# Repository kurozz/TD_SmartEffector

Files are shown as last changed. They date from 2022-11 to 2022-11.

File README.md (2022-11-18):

# Tree Diagram Smart Effector design files repository.

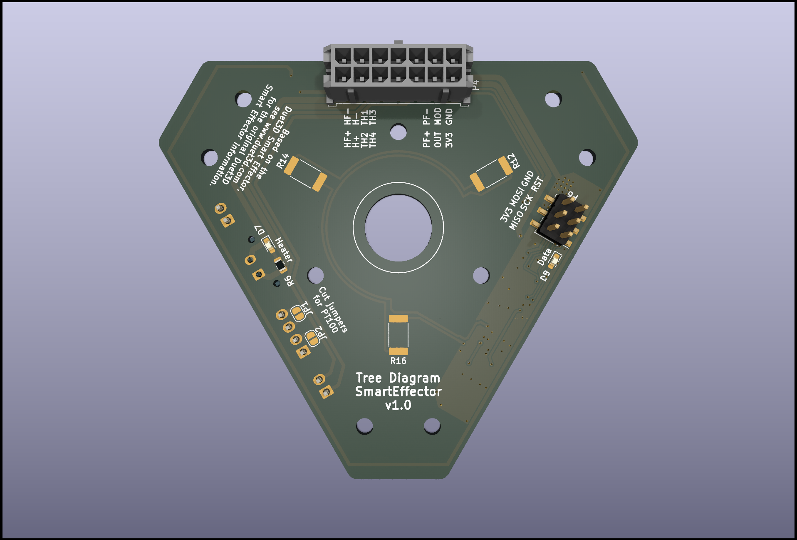
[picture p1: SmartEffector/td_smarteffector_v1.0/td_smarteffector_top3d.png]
Top 3D View

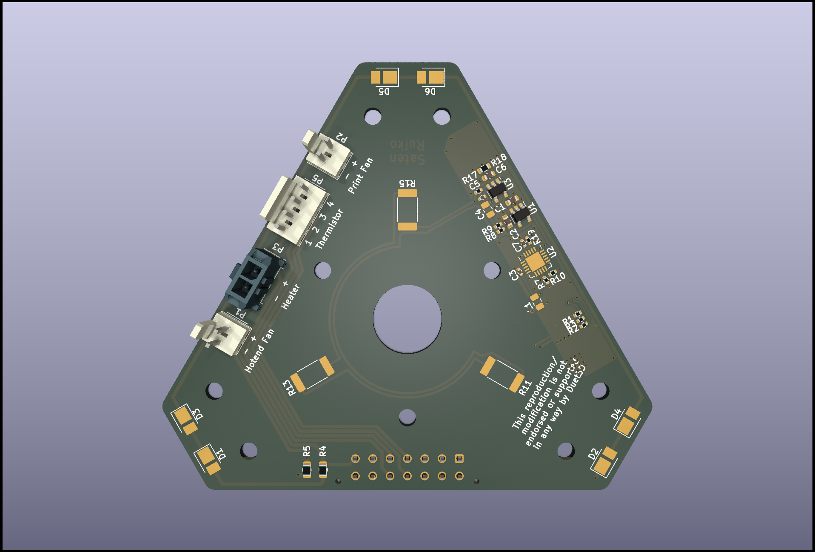
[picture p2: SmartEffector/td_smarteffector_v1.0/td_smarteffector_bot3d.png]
Bottom 3D View


Based on the Duet3D Smart Effector, see www.duet3d.com for the original Duet3D Smart Effector information. This reproduction/modification is not endorsed or supported in any way by Duet3D

This design is meant for 24V, 12V is possible but requires dessoldering LEDs and adding jumpers.

## Changes from the original Smart Effector v3.0:
- Connectors heavily modified
    - All cables from the Duet controller board on a single connector
    - All cables from the effector on the same side of the board
- 6 illumination LEDs instead of 3.
- LEDs are 24V only. You can use 12V by soldering jumpers in place of 3 LEDs.
- Different regulator and amplifier to be easier to source.
- Works with the same firmware as Smart Effector v3.0.

Tree Diagram Smart Effector

Design by Kuro.

Original Design by Tony Lock and David Crocker

LICENSE: see the LICENSE file in the repository

Documentation: https://docs.duet3d.com/Duet3D_hardware/Accessories/Smart_Effector

Developed in KiCAD v6: https://www.kicad.org/

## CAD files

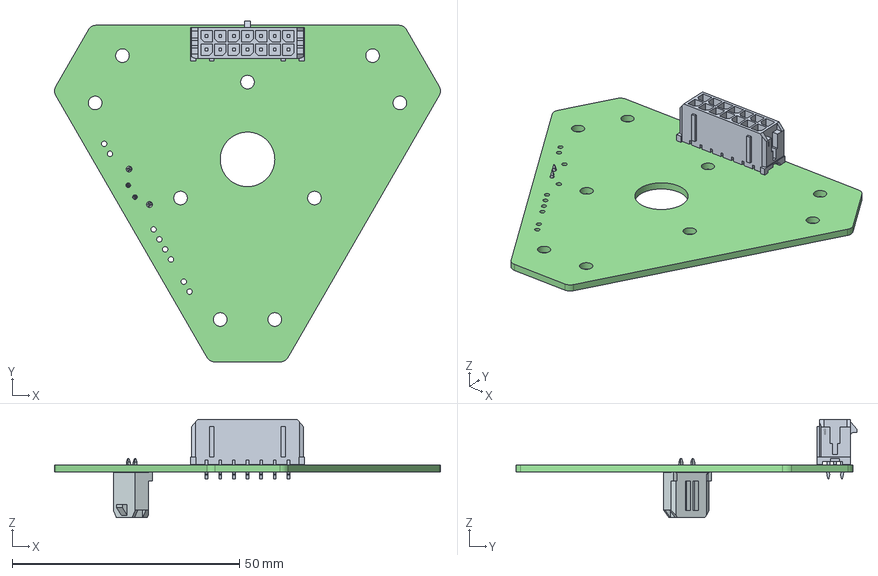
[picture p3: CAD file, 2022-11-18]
SmartEffector/td_smarteffector_v1.0/td_smarteffector.step
84.9 x 75.0 x 21.7 mm
td_smarteffector PCB

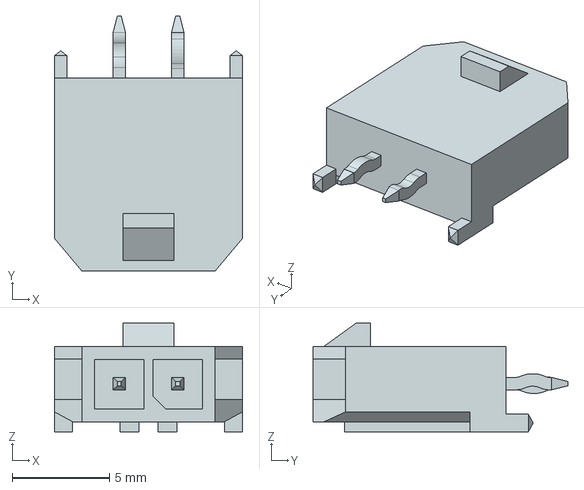
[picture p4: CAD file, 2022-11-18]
SmartEffector/td_smarteffector_v1.0/3dmodel/436500215.stp
9.65 x 13.1 x 5.57 mm

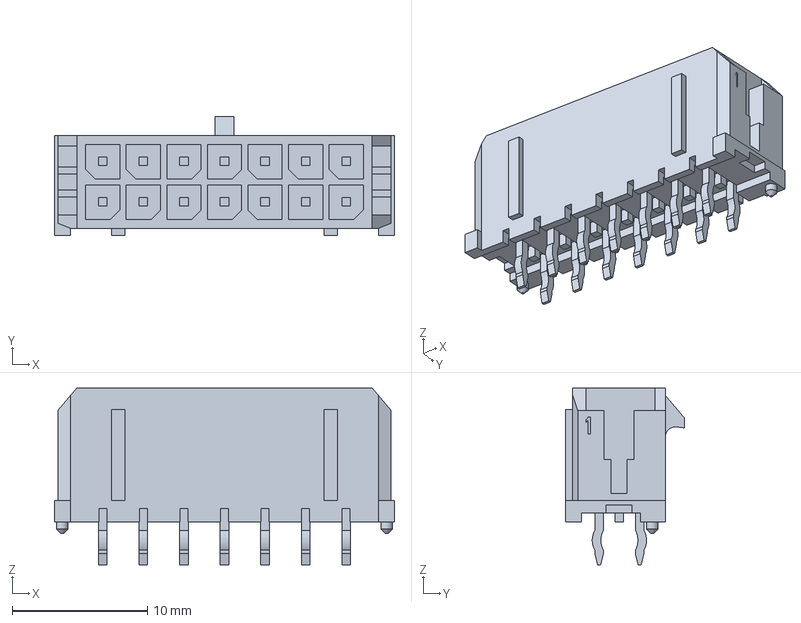
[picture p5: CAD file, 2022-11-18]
SmartEffector/td_smarteffector_v1.0/3dmodel/430451412.stp
25.1 x 8.77 x 13.1 mm

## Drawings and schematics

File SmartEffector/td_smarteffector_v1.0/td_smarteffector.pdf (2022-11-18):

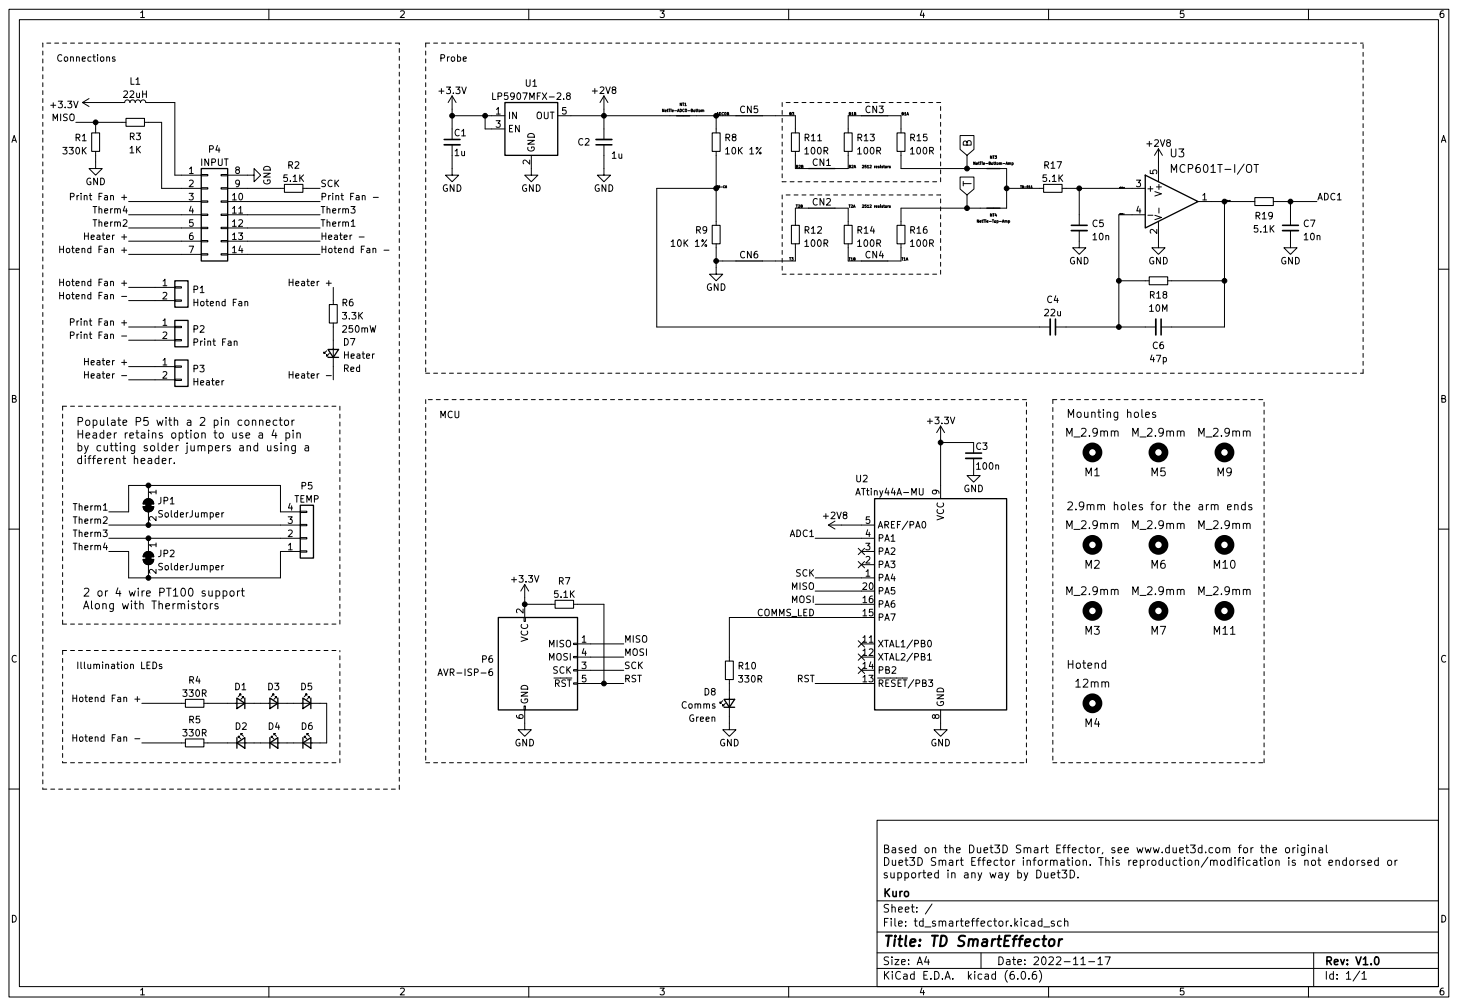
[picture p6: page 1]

Header retains option to use a 4 pin
by cutting solder jumpers and using a

Illumination LEDs 2 or 4 wire PT100 support
Along with Thermistors

2 SCK 3 MOSI 4 ~{RST} 5 GND

supported in any way by Duet3D. GND

File: td_smarteffector.kicad_sch Sheet: / Kuro Based on the Duet3D Smart Effector, see www.duet3d.com for the original

Duet3D Smart Effector information. This reproduction/modification is not endorsed or

Id: 1/1 Title: TD SmartEffector

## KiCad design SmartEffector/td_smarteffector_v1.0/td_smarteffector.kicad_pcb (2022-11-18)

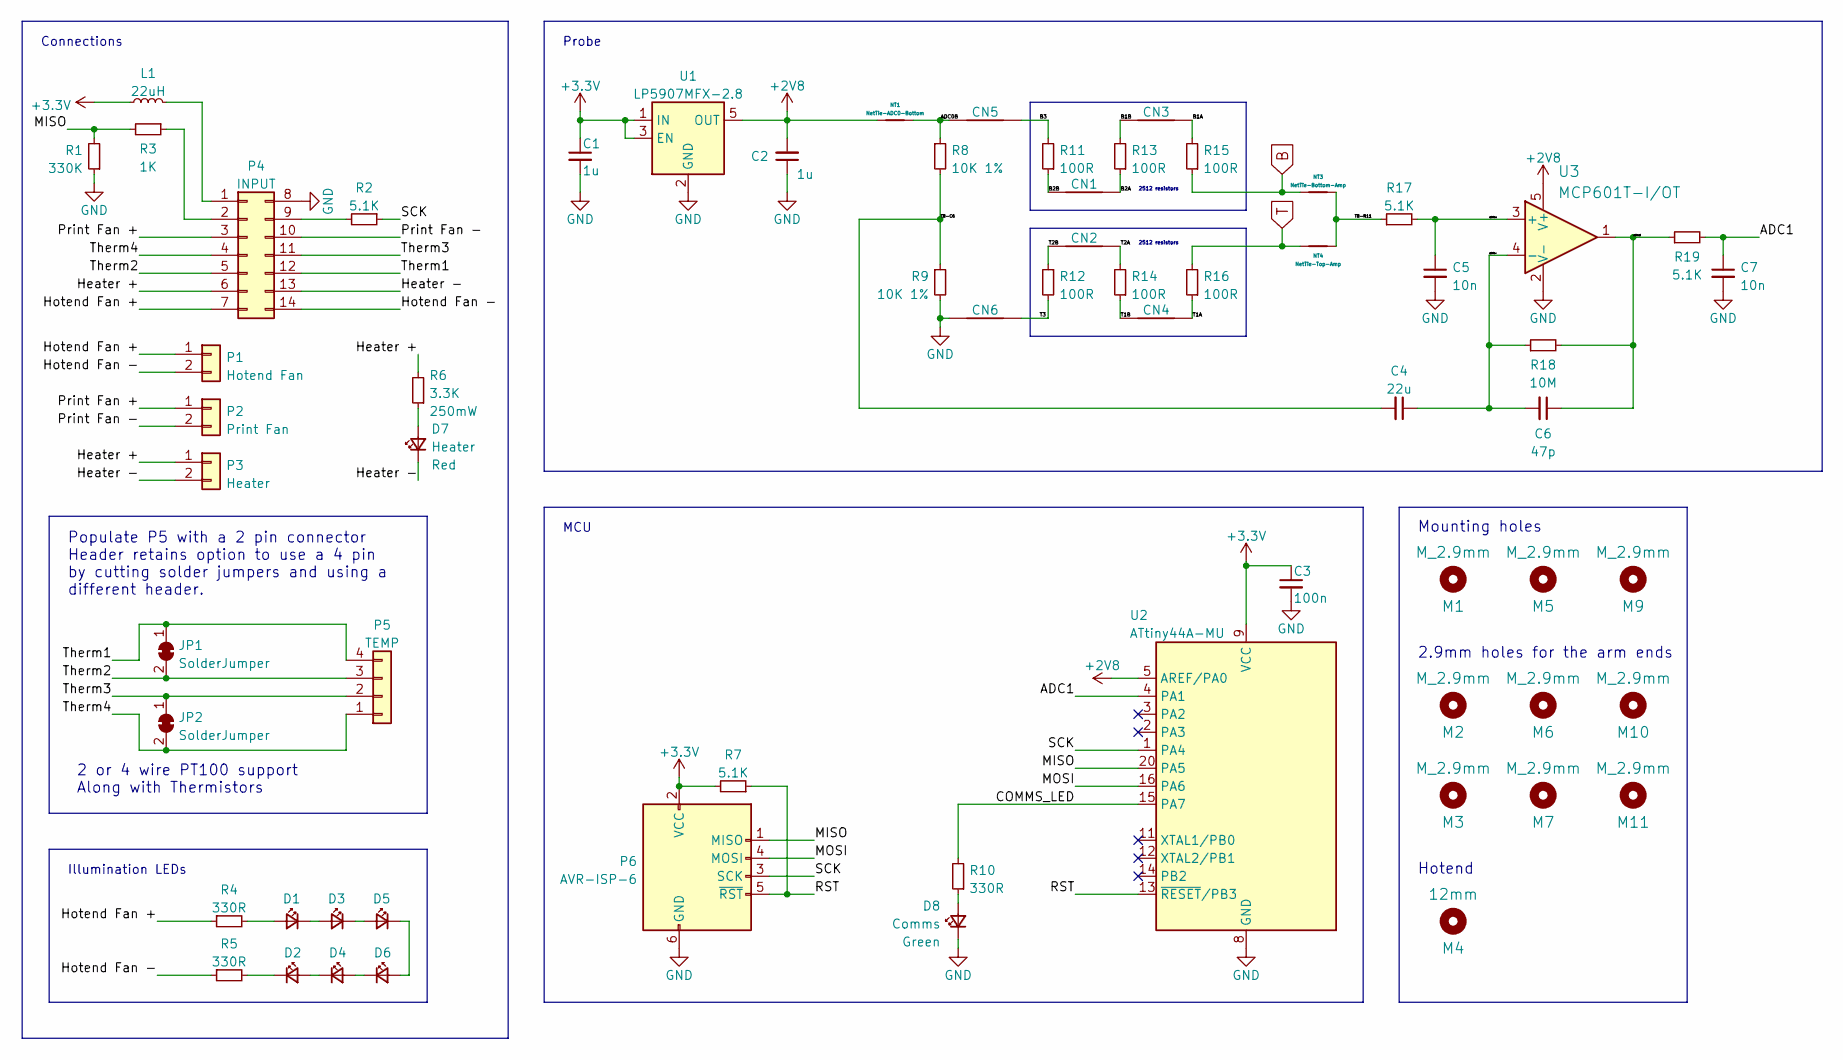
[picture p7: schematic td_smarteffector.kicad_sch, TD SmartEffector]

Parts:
C1, C2: 1u; C_0603_1608Metric; LCSC C15849
C3: 100n; C_0402_1005Metric; LCSC C307331
C4: 22u; C_0805_2012Metric; LCSC C602037
C5, C7: 10n; C_0402_1005Metric; LCSC C15195
C6: 47p; C_0603_1608Metric; LCSC C1671
CN1, CN3: Round_Track_Connector; round_track_connection_bot_01
CN2, CN4: Round_Track_Connector; round_track_connection_top_01
CN5: Round_Track_Connector; round_track_connection_bot_02
CN6: Round_Track_Connector; round_track_connection_top_02
D1, D2, D3, D4, D5, D6: illum; LED_PLCC_2835_Handsoldering
D7: Heater; LED_0603_1608Metric_Pad1.05x0.95mm_HandSolder
D8: Comms; LED_0603_1608Metric_Pad1.05x0.95mm_HandSolder
JP1, JP2: SolderJumper; SolderJumper-2_P1.3mm_Bridged_RoundedPad1.0x1.5mm
L1: 22uH; L_0805_2012Metric; LCSC C223175
M1, M2, M3, M5, M6, M7, M9, M10, M11: M_2.9mm; MountingHole_3mm
M4: 12mm; 12mmHole
NT1: NetTie-ADC0-Bottom; NetTie-2_SMD_Pad0.5mm
NT3: NetTie-Bottom-Amp; NetTie-2_SMD_Pad0.5mm
NT4: NetTie-Top-Amp; NetTie-2_SMD_Pad0.5mm
P1: Hotend Fan; Molex_KK-254_AE-6410-02A_1x02_P2.54mm_Vertical
P2: Print Fan; Molex_KK-254_AE-6410-02A_1x02_P2.54mm_Vertical
P3: Heater; Molex_Micro-Fit_3.0_43650-0215_1x02_P3.00mm_Vertical
P4: INPUT; Molex_Micro-Fit_3.0_43045-1412_2x07_P3.00mm_Vertical
P5: TEMP; Molex_KK-254_AE-6410-04A_1x04_P2.54mm_Vertical
P6: AVR-ISP-6; PinHeader_2x03_P2.54mm_Vertical_SMD
R1: 330K; R_0402_1005Metric; LCSC C25778
R2, R7, R17, R19: 5.1K; R_0402_1005Metric; LCSC C25905
R3: 1K; R_0402_1005Metric; LCSC C11702
R4, R5: 330R; R_0805_2012Metric; LCSC C17630
R6: 3.3K; R_0805_2012Metric; LCSC C2759303
R8, R9: 10K 1%; R_0402_1005Metric; LCSC C25744
R10: 330R; R_0402_1005Metric; LCSC C25104
R11, R12, R13, R14, R15, R16: 100R; R_2512_6332Metric; LCSC C309610
R18: 10M; R_0603_1608Metric; LCSC C7250
U1: LP5907MFX-2.8; SOT-23-5; Part Number LP5907MFX-2.8/NOPB; LCSC C186700
U2: ATtiny44A-MU; QFN-20-1EP_4x4mm_P0.5mm_EP2.6x2.6mm; Part Number ATtiny44A-MUR; LCSC C123718
U3: MCP601T-I/OT; SOT-23-5; Part Number MCP601T-I/OT; LCSC C128440

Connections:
+2V8: C2.2, NT1.1, U1.5 (OUT), U2.5 (AREF/PA0), U3.5 (V+)
+3V3: C1.1, C3.1, L1.1, P6.2 (VCC), R7.2, U1.1 (IN), U1.3 (EN), U2.9 (VCC)
/ADC0B: CN5.1, NT1.2, R8.1
/ADC1: C7.1, R19.2, U2.4 (PA1)
/B1A: CN3.1, R15.2
/B1B: CN3.2, R13.2
/B2A: CN1.1, R13.1
/B2B: CN1.2, R11.1
/B3: CN5.2, R11.2
/COMMS_LED: R10.2, U2.15 (PA7)
/Heater +: P3.1, P4.6, R6.2
/Heater -: D7.1 (K), P3.2, P4.13
/Hotend Fan +: P1.1, P4.7, R4.1
/Hotend Fan -: P1.2, P4.14, R5.1
/MISO: P6.1 (MISO), R1.2, R3.2, U2.20 (PA5)
/MOSI: P6.4 (MOSI), U2.16 (PA6)
/Print Fan +: P2.1, P4.3
/Print Fan -: P2.2, P4.10
/RST: P6.5 (~RST), R7.1, U2.13 (~RESET/PB3)
/SCK: P6.3 (SCK), R2.1, U2.1 (PA4)
/T1A: CN4.1, R16.1
/T1B: CN4.2, R14.1
/T2A: CN2.1, R14.2
/T2B: CN2.2, R12.1
/T3: CN6.2, R12.2
/TB-C6: C4.2, R8.2, R9.1
/TB-R11: NT3.2, NT4.2, R17.1
/Therm1: JP1.1 (A), P4.12, P5.4
/Therm2: JP1.2 (B), P4.5, P5.3
/Therm3: JP2.1 (A), P4.11, P5.2
/Therm4: JP2.2 (B), P4.4, P5.1
/u3Vout: C6.1, R18.2, R19.1, U3.1
/u3vin+: C5.1, R17.2, U3.3 (+)
/u3vin-: C4.1, C6.2, R18.1, U3.4 (-)
B: NT3.1, R15.1
GND: C1.2, C2.1, C3.2, C5.2, C7.2, CN6.1, D8.1 (K), P4.8, P6.6 (GND), R1.1, R9.2, U1.2 (GND), U2.8 (GND), U2.21 (GND), U3.2 (V-)
unnamed: D1.1 (K), D3.2 (A)
unnamed: D1.2 (A), R4.2
unnamed: D2.1 (K), R5.2
unnamed: D2.2 (A), D4.1 (K)
unnamed: D3.1 (K), D5.2 (A)
unnamed: D4.2 (A), D6.1 (K)
unnamed: D5.1 (K), D6.2 (A)
unnamed: D7.2 (A), R6.1
unnamed: D8.2 (A), R10.1
unnamed: L1.2, P4.1
unnamed: P4.2, R3.1
unnamed: P4.9, R2.2
T: NT4.1, R16.2

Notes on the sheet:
2.9mm holes for the arm ends
2512 resistors
Mounting holes
Hotend
Probe
MCU
Populate P5 with a 2 pin connector Header retains option to use a 4 pin by cutting solder jumpers and using a different header.
Illumination LEDs
Connections
2 or 4 wire PT100 support Along with Thermistors

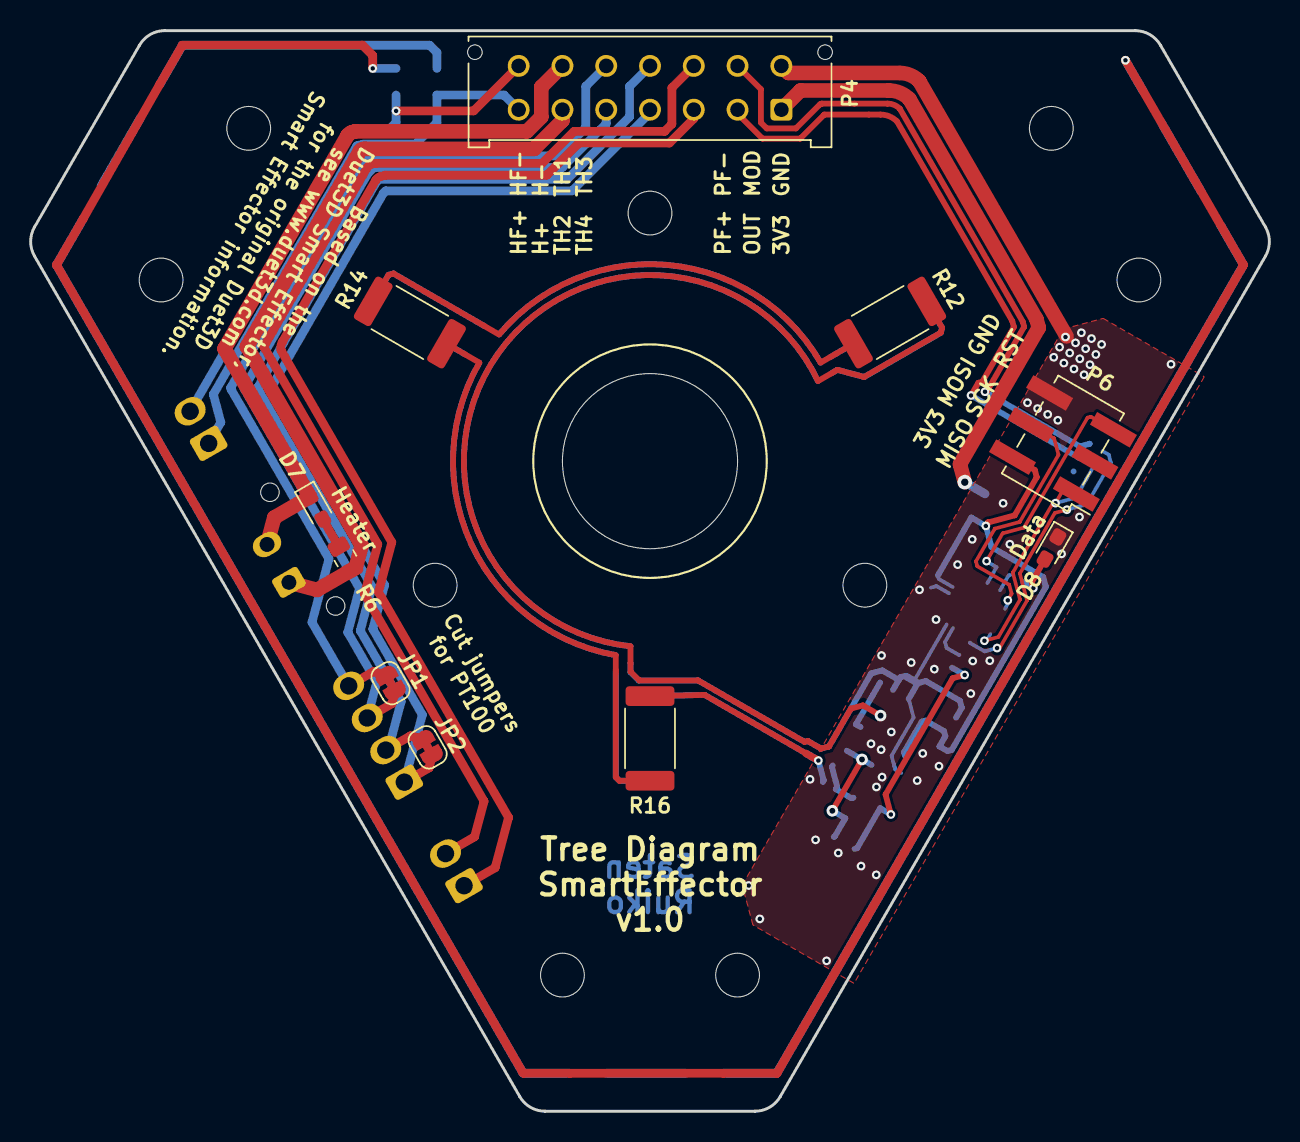
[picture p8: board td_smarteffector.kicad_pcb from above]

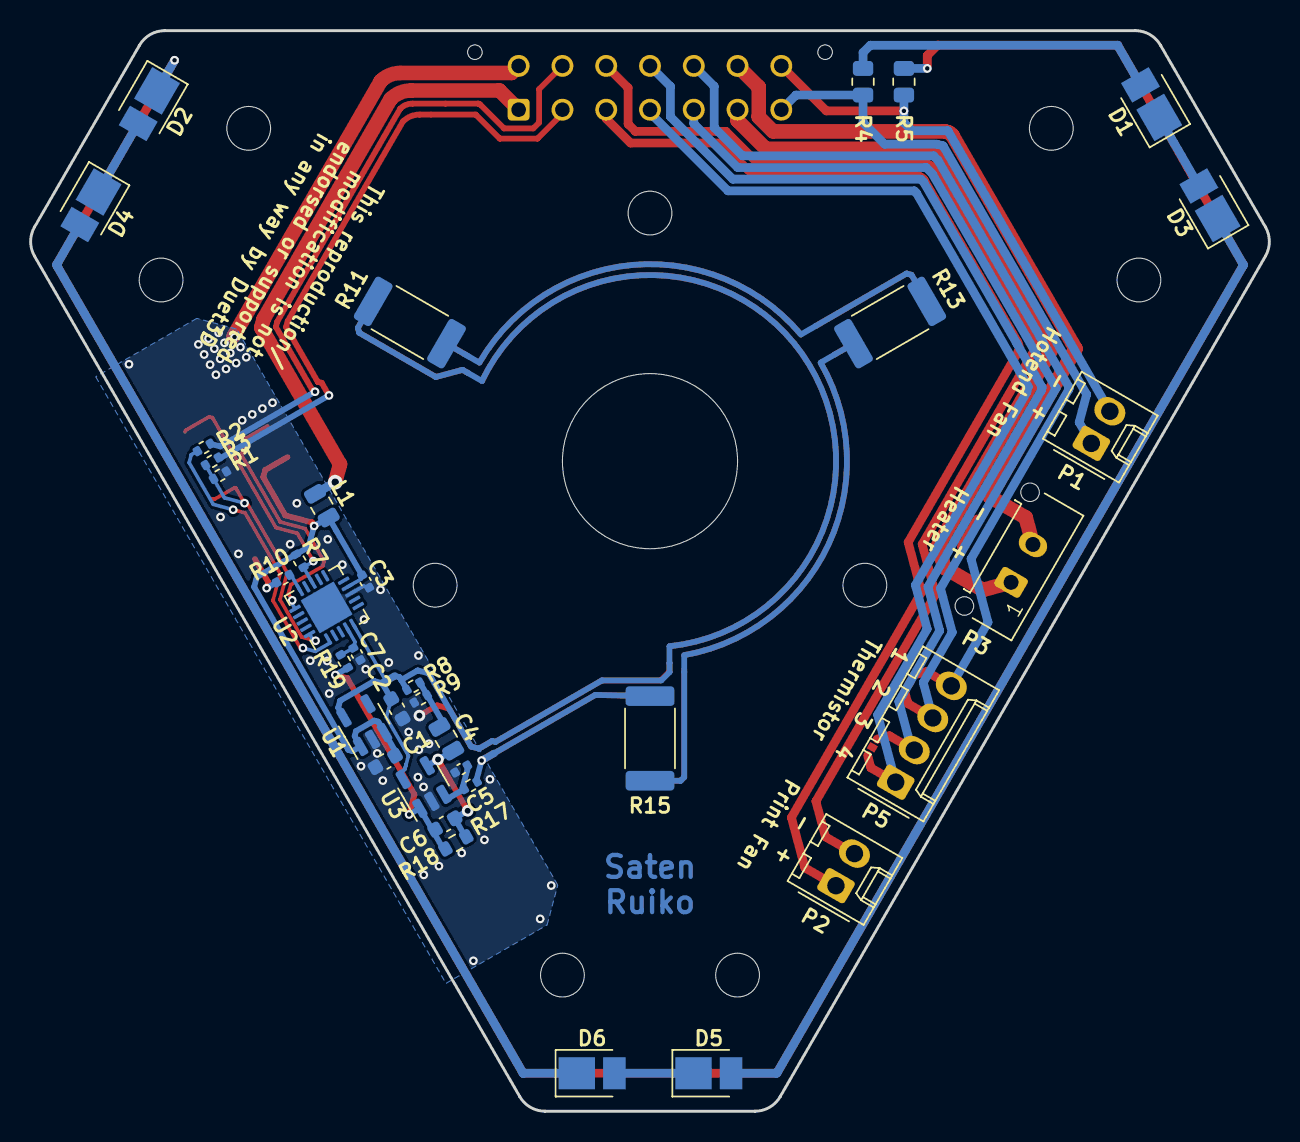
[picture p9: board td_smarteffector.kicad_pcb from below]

Board: 2 copper layers, 84.9 x 74.0 mm, 65 parts (38 on the bottom side), 49 nets.

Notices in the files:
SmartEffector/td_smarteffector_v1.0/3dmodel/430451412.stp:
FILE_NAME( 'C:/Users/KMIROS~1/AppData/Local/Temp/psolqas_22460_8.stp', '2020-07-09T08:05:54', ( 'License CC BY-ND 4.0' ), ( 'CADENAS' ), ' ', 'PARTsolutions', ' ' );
